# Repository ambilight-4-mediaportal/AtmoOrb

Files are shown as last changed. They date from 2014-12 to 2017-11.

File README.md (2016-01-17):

# AtmoOrb

Projects / showcases using AtmoOrb:

### ESP8266
http://forum.team-mediaportal.com/threads/diy-atmoorb-a-hue-like-mood-lamp-based-on-arduino-esp8266-wifi-module-and-ws2812b-rgb-leds.129229/

### Spark / Particle (Core / Photon)
http://forum.team-mediaportal.com/threads/diy-atmoorb-a-hue-like-mood-lamp-based-on-particle-photon-with-neopixel-tutorial-added.131901/

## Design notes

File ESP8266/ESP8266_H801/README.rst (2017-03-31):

H801 AtmoORB code with status indication
------------------------------------------------------------------------------

The H801 is a very affordable (roughly $10 on Aliexpress) ESP8266 based Wifi
RGB Led controller. It has 5 mosfets accepting input from `5v` to `24v` up to
`4A` with the default configuration. Note that this controller is meant for
dumb RGB(WW) led strips which are _not_ addressable.

The H801 uses `20N06L` mosfets which actually support up to `20A` but I suspect
the rest of the board would burn up if you actually tried it. If you plan to go
beyond the recommend `4A` you should at the very least add some heatsinks to
the mosfets.

The code here makes your H801 behave as a regular AtmoORB but adds a few small
features over the regular ESP8266 code.

1. Since this controller doesn't support addressable leds it drivers the
   mosfets straight away.
2. The controller shows it's status with the 2 status lights on-board.

   1. Whenever the H801 is connected to the wifi network the green led should
      be on.
   2. When the H801 is connecting to the wifi the red led will flash
      periodically (twice per second).
   3. Whenever data is received the red led will flash.

To be able to flash the H801 you will need to solder the headers on the print
yourself. Programming can be done with a regular FTDI programmer but note that
the module _only_ accepts `3.3v` and _will_ burn out if you feed it `5v`.

Some documentation can be found here:
https://eryk.io/2015/10/esp8266-based-wifi-rgb-controller-h801/

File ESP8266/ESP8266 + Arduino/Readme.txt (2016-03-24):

This AtmoOrb version is using an Arduino for the processing and an ESP8266 for WiFi. They communicate via UART (serial) with each other and the EPS8266 AT commands are utilized.
This is an outdated approach and is only kept for legacy support.

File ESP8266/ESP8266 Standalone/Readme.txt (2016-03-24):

You will need to add the ESP8266 platform package to your Arduino IDE Board Manager.
Please follow these installation steps: https://github.com/esp8266/Arduino

Please also make sure that you are using the latest FastLED files.
https://github.com/FastLED/FastLED/archive/master.zip

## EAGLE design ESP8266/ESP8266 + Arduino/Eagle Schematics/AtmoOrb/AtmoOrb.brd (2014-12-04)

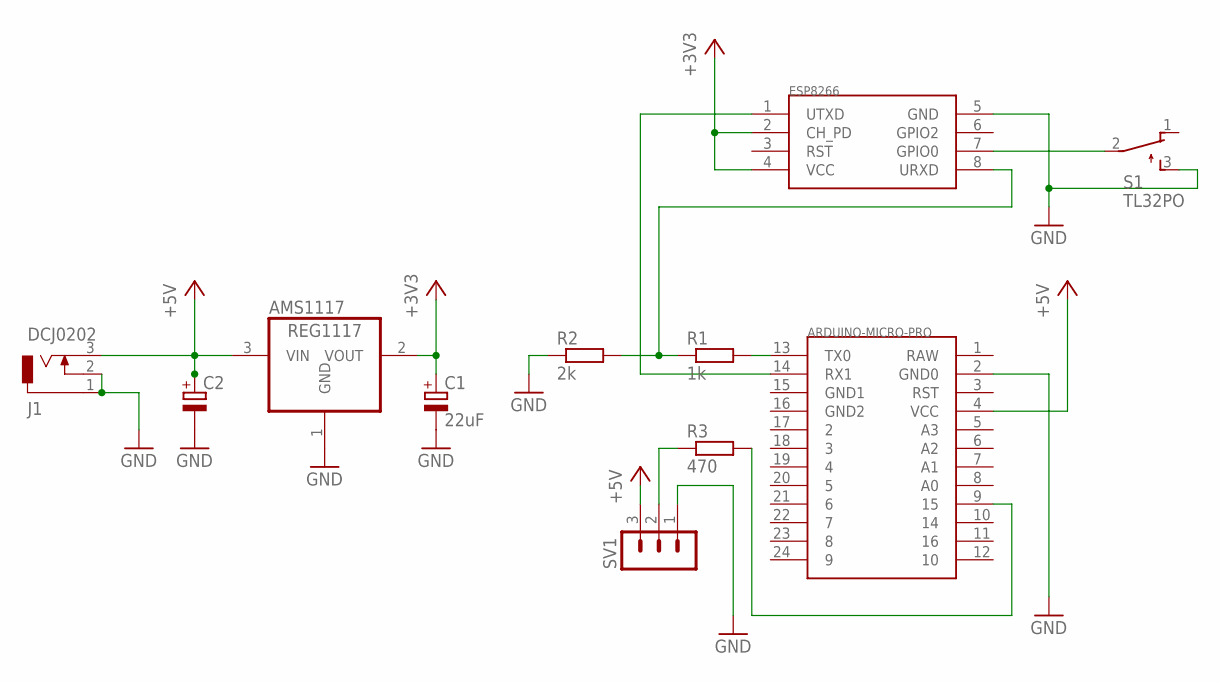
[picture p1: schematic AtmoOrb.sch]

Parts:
AMS1117: REG1117; SOT223
ARDUINO-MICRO-PRO: ARDUINO_MICRO_PRO
C1: 22uF; TAP5-60
C2: CPOL-EUTAP5-60; TAP5-60
ESP8266: ESP8266
J1: DCJ0202
R1: 1k; 0207/10
R2: 2k; 0207/10
R3: 470; 0207/10
S1: TL32PO; TL3XPO
SV1: MA03-1

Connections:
+3V3: AMS1117.2 (VOUT), C1.+, ESP8266.2 (CH_PD), ESP8266.4 (VCC)
+5V: AMS1117.3 (VIN), ARDUINO-MICRO-PRO.4 (VCC), C2.+, J1.3, SV1.3
GND: AMS1117.1 (GND), ARDUINO-MICRO-PRO.2 (GND0), C1.-, C2.-, ESP8266.5 (GND), J1.1, J1.2, R2.1, S1.3 (S), SV1.1
unnamed: ARDUINO-MICRO-PRO.13 (TX0), R1.2
unnamed: ESP8266.8 (URXD), R1.1, R2.2
unnamed: ARDUINO-MICRO-PRO.14 (RX1), ESP8266.1 (UTXD)
unnamed: ARDUINO-MICRO-PRO.9 (15), R3.2
unnamed: R3.1, SV1.2
unnamed: ESP8266.7 (GPIO0), S1.2

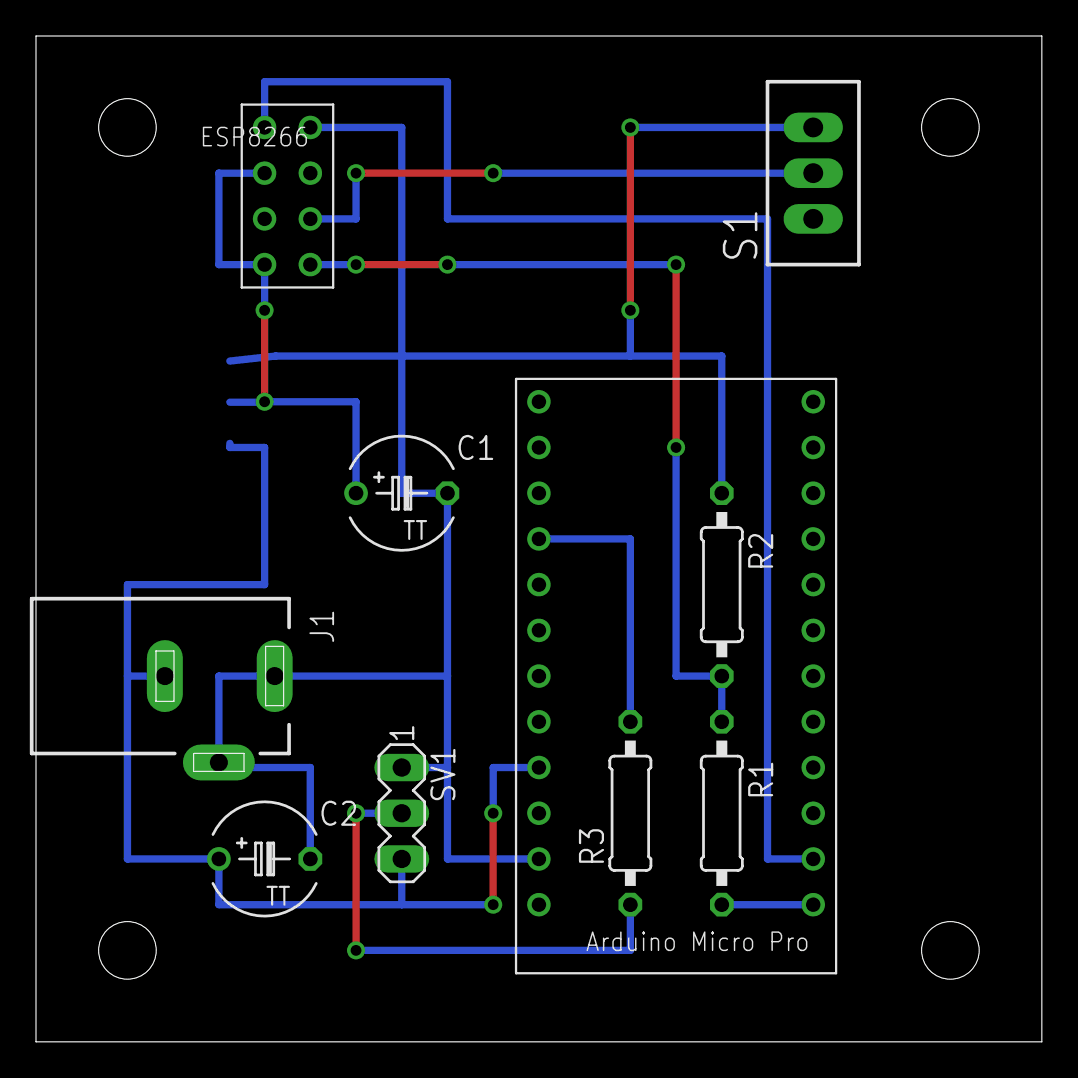
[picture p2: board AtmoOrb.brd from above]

Board: 2 copper layers, 55.9 x 55.9 mm, 11 parts (1 on the bottom side), 9 nets.

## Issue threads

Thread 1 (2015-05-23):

Hyperion support

iLLiac4, 2015-05-23:
Hi. Since it is a remote and it uses actually only one color at the time it would be usefull to try something with ordinary rgb led stripe with pwm and arduino.

Lightning303, 2015-05-24:
Hey,
not sure what exactly you want. Hyperion support or support for "analog" leds stripes? Either way, i am not going to implement these. However, you are of course free to do so :).

Closed 2016-02-05.

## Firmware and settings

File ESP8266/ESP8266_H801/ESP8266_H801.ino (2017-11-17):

// AtmoOrb H801 by Wolph, Lightning303 & Rick164
//
// H801 (ESP8266 based) Version
//
//
// You may change the settings that are commented

#include <ESP8266WiFi.h>
#include <WiFiUDP.h>

#define NUM_LEDS 24 // Number of leds
#define DATA_PIN 7 // Data pin for leds (the default pin 7 might correspond to pin 13 on some boards)
#define SERIAL_DEBUG 1 // Serial debugging (0=Off, 1=On)

#define ID 1 // Id of this lamp

// Smoothing
#define SMOOTH_STEPS 20 // Steps to take for smoothing colors
#define SMOOTH_DELAY 10 // Delay between smoothing steps
#define SMOOTH_BLOCK 0 // Block incoming colors while smoothing

// Startup color
#define STARTUP_RED 255 // Color shown directly after power on
#define STARTUP_GREEN 175 // Color shown directly after power on
#define STARTUP_BLUE 100 // Color shown directly after power on

// White adjustment
#define RED_CORRECTION 220 // Color Correction
#define GREEN_CORRECTION 255 // Color Correction
#define BLUE_CORRECTION 180 // Color Correction

// LED pins
#define PIN_RED 15
#define PIN_GREEN 13
#define PIN_BLUE 12
#define PIN_WHITE1 14
#define PIN_WHITE2 4
#define PIN_STATUS_GREEN 1
#define PIN_STATUS_RED 5

#define ON LOW
#define OFF HIGH

// Network settings
const char* ssid = "ssid"; // WiFi SSID
const char* password = "password"; // WiFi password
const IPAddress multicastIP(239, 15, 18, 2); // Multicast IP address
const int multicastPort = 49692; // Multicast port number

WiFiUDP Udp;
byte nextColor[3];
byte prevColor[3];
byte currentColor[3];
byte smoothStep = SMOOTH_STEPS;
unsigned long smoothMillis;

void setColor(byte red, byte green, byte blue);
void setSmoothColor(byte red, byte green, byte blue);
void smoothColor();
void clearSmoothColors();

void wifiConnect() {
  digitalWrite(PIN_STATUS_GREEN, OFF);
  digitalWrite(PIN_STATUS_RED, OFF);

  int i = 0;
  Serial1.print(F("Connecting to "));
  Serial1.println(ssid);

  while (WiFi.status() != WL_CONNECTED)
  {
    delay(250);
    if (i++ % 2) {
      /* Enable status led */
      digitalWrite(PIN_STATUS_RED, ON);

      /* Write to the console if needed */
#if SERIAL_DEBUG == 1
      Serial1.print(F("."));
#endif
    } else {
      /* Disable status led */
      digitalWrite(PIN_STATUS_RED, OFF);
    }
  }

  /* Enable the green led when connected to Wifi */
  digitalWrite(PIN_STATUS_RED, OFF);
  digitalWrite(PIN_STATUS_GREEN, ON);

#if SERIAL_DEBUG == 1
  Serial1.println("");
  Serial1.print(F("Connected to "));
  Serial1.println(ssid);
  Serial1.print(F("IP address: "));
  Serial1.println(WiFi.localIP());
#endif
}

void setup()
{
  pinMode(PIN_RED, OUTPUT);
  pinMode(PIN_GREEN, OUTPUT);
  pinMode(PIN_BLUE, OUTPUT);
  pinMode(PIN_WHITE1, OUTPUT);
  pinMode(PIN_WHITE2, OUTPUT);
  pinMode(PIN_STATUS_GREEN, OUTPUT);
  pinMode(PIN_STATUS_RED, OUTPUT);

#if SERIAL_DEBUG == 1
  Serial1.begin(115200);
#endif

  WiFi.mode(WIFI_STA);
  WiFi.begin(ssid, password);
  wifiConnect();

  Udp.beginMulticast(WiFi.localIP(), multicastIP, multicastPort);
}

void loop()
{
  if (WiFi.status() != WL_CONNECTED)
  {
#if SERIAL_DEBUG == 1
    Serial1.print(F("Lost connection to "));
    Serial1.print(ssid);
    Serial1.println(F("."));
    Serial1.println(F("Trying to reconnect."));
#endif

    wifiConnect();
  }

  if (Udp.parsePacket())
  {
    digitalWrite(PIN_STATUS_RED, ON);
    
    byte len = Udp.available();
    byte rcvd[len];
    Udp.read(rcvd, len);

#if SERIAL_DEBUG == 1
    Serial1.print(F("UDP Packet from "));
    Serial1.print(Udp.remoteIP());
    Serial1.print(F(" to "));
    Serial1.println(Udp.destinationIP());
    for (byte i = 0; i < len; i++)
    {
      Serial1.print(rcvd[i]);
      Serial1.print(F(" "));
    }
    Serial1.println("");
#endif
    if (len >= 8 && rcvd[0] == 0xC0 && rcvd[1] == 0xFF && rcvd[2] == 0xEE && (rcvd[4] == ID || rcvd[4] == 0))
    {
      switch (rcvd[3])
      {
        case 1:
          setColor(0, 0, 0);
          smoothStep = SMOOTH_STEPS;
          break;
        case 2:
        default:
          setSmoothColor(rcvd[5], rcvd[6], rcvd[7]);
          break;
        case 4:
          setColor(rcvd[5], rcvd[6], rcvd[7]);
          smoothStep = SMOOTH_STEPS;
          break;
        case 8:
          Udp.beginPacket(Udp.remoteIP(), Udp.remotePort());
          Udp.write(ID);
          Udp.endPacket();
          break;
      }
    }
    digitalWrite(PIN_STATUS_RED, OFF);
  }
  if (smoothStep < SMOOTH_STEPS && millis() >= (smoothMillis + (SMOOTH_DELAY * (smoothStep + 1))))
  {
    smoothColor();
  }
}

// Display color on leds
void setColor(byte red, byte green, byte blue)
{
  // Is the new color already active?
  if (currentColor[0] == red && currentColor[1] == green && currentColor[2] == blue)
  {
    return;
  }
  currentColor[0] = red;
  currentColor[1] = green;
  currentColor[2] = blue;

  analogWrite(PIN_RED, red * 4);
  analogWrite(PIN_GREEN, green * 4);
  analogWrite(PIN_BLUE, blue * 4);
}

// Set a new color to smooth to
void setSmoothColor(byte red, byte green, byte blue)
{
  if (smoothStep == SMOOTH_STEPS || SMOOTH_BLOCK == 0)
  {
    // Is the new color the same as the one we already are smoothing towards?
    // If so dont do anything.
    if (nextColor[0] == red && nextColor[1] == green && nextColor[2] == blue)
    {
      return;
    }
    // Is the new color the same as we have right now?
    // If so stop smoothing and keep the current color.
    else if (currentColor[0] == red && currentColor[1] == green && currentColor[2] == blue)
    {
      smoothStep = SMOOTH_STEPS;
      return;
    }

    prevColor[0] = currentColor[0];
    prevColor[1] = currentColor[1];
    prevColor[2] = currentColor[2];

    nextColor[0] = red;
    nextColor[1] = green;
    nextColor[2] = blue;

    smoothMillis = millis();
    smoothStep = 0;
  }
}

// Display one step to the next color
void smoothColor()
{
  smoothStep++;

  byte red = prevColor[0] + (((nextColor[0] - prevColor[0]) * smoothStep) / SMOOTH_STEPS);
  byte green = prevColor[1] + (((nextColor[1] - prevColor[1]) * smoothStep) / SMOOTH_STEPS);
  byte blue = prevColor[2] + (((nextColor[2] - prevColor[2]) * smoothStep) / SMOOTH_STEPS);

  setColor(red, green, blue);
}

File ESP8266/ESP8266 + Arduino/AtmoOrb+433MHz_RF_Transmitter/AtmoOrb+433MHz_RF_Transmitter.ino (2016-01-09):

// AtmoOrb by Lightning303
//
// Developed for:
// "Arduino" Micro Pro
// ESP8266 Module Version 02
// Firmware Version: 0018000902-AI03 (AT 0.18 & SDK 0.9.2)
//
// Pin Connections:
//
// ESP8266
// UTXD           Arduino RX1
// URXD           Arduino TX0 (ESP8266 is 3.3V!)
// VCC            VCC (ESP8266 is 3.3V!)
// GND            GND
// CH_PD          VCC (ESP8266 is 3.3V!)
//
// Arduino
// RX1            ESP8266 UTXD
// TX0            ESP8266 URXD (ESP8266 is 3.3V!)
// VCC            VCC
// GND            GND
// 15             WS2812B Data
//
//
// We are using a baud rate of 19200 here.
// You can either change the ESP8266 baudrate with "AT+CIOBAUD=..."
// or change the program to use another one by editing "Serial1.begin(19200);"

#include "FastLED.h"
#include <RCSwitch.h>

#define NUM_LEDS 27 // Number of leds
#define DATA_PIN 15 // Data pin for leds
#define SLEEP_DELAY 900000 // Delay until RF transmitter sends signals

#define ID "1" // Id of this lamp (can be string or integer)

// Network settings
#define WIFI_SSID "Your WiFi SSID" // SSID of your wifi network
#define WIFI_PASSWORD "Your WiFi Password" // Password to your wifi network
#define DISABLE_DHCP 0 // Disable DHCP
#define STATIC_IP "192.168.1.42" // Static ip if DHCP is disabled
#define BROADCAST_IP "192.168.1.255" // Broadcast ip of your network
#define PORT 49692 // Port you want to use for broadcasting and for the server

// Smoothing
#define SMOOTH_STEPS 50 // Steps to take for smoothing colors
#define SMOOTH_DELAY 4 // Delay between smoothing steps
#define SMOOTH_BLOCK 0 // Block incoming colors while smoothing

// Startup color
#define STARTUP_RED 255
#define STARTUP_GREEN 175
#define STARTUP_BLUE 100

// White adjustment
#define RED_CORRECTION 220
#define GREEN_CORRECTION 255
#define BLUE_CORRECTION 180


CRGB leds[NUM_LEDS];
RCSwitch mySwitch = RCSwitch();
char serialBuffer[500];
String ip;
boolean initialStart = false;
unsigned long previousCheckIP = 0; 
int checkIPInterval = 5000;
byte nextColor[3];
byte prevColor[3];
byte currentColor[3];
byte smoothStep = SMOOTH_STEPS;
unsigned long smoothMillis;
char* readyString = "ready";
char* okString = "OK";
char* noChangeString = "no change";


void setup()
{
  TXLED1;

  FastLED.addLeds<WS2812B, DATA_PIN, GRB>(leds, NUM_LEDS);
  //FastLED.setCorrection(TypicalSMD5050);
  FastLED.setCorrection(CRGB(RED_CORRECTION, GREEN_CORRECTION, BLUE_CORRECTION));

  setSmoothColor(STARTUP_RED, STARTUP_GREEN, STARTUP_BLUE);
  
  mySwitch.enableTransmit(8);
  
  Serial.begin(115200);
  Serial.setTimeout(5);
  Serial1.begin(19200);
  Serial1.setTimeout(5000); 

  // Reset ESP8266
  Serial1.println(F("AT+RST"));
  Serial1.find(readyString);

  // Change to Station mode
  Serial1.println(F("AT+CWMODE=1"));
  Serial1.find(noChangeString);

  // Reset ESP8266
  Serial1.println(F("AT+RST"));
  Serial1.find(readyString);

  // Disable DHCP
  if (DISABLE_DHCP == 1)
  {
    Serial1.println(F("AT+CWDHCP=2,1"));
    Serial1.find(okString);
  }

  // Join access point
  Serial1.setTimeout(10000);
  Serial1.print(F("AT+CWJAP=\""));
  Serial1.print(WIFI_SSID);
  Serial1.print(F("\",\""));
  Serial1.print(WIFI_PASSWORD);
  Serial1.println(F("\""));
  Serial1.find(okString);
  Serial1.setTimeout(5000);

  // Set static ip
  if (DISABLE_DHCP == 1)
  {
    Serial1.print(F("AT+CIPSTA=\""));
    Serial1.print(STATIC_IP);
    Serial1.println(F("\""));
    Serial1.find(okString);
  }

  // Enable multiple connections
  Serial1.println(F("AT+CIPMUX=1"));
  Serial1.find(okString);

  // Setup server
  Serial1.print(F("AT+CIPSERVER=1,"));
  Serial1.println(PORT);
  Serial1.find(okString);

  // Setup client
  Serial1.print(F("AT+CIPSTART=2,\"UDP\",\""));
  Serial1.print(BROADCAST_IP);
  Serial1.print(F("\","));
  Serial1.println(PORT);
  Serial1.find(okString);
  Serial1.setTimeout(5);  
}

void loop()
{
  digitalWrite(17, HIGH);
  if (Serial1.available() > 0)
  {
    int len = Serial1.readBytes(serialBuffer, sizeof(serialBuffer));
    String message = String(serialBuffer).substring(0,len-1);

    // AT 0.20 ip syntax
    if (message.indexOf(F("+CIFSR:")) > -1)
    {
      if (message.indexOf(F("+CIFSR:STAIP")) > -1)
      {
        int start = message.indexOf(F("+CIFSR:STAIP"));
        start = message.indexOf(F("\""), start) + 1; 
        if (isValidIp4(message.substring(start, message.indexOf(F("\""), start))) > 0)
        {
          ip = message.substring(start, message.indexOf(F("\""), start));
          ipReceived();
        }
      }
    }
    // AT pre 0.20 ip syntax
    else if (message.indexOf(F("AT+CIFSR")) > -1)
    {
      int start = message.indexOf(F("AT+CIFSR"));
      start = message.indexOf(F("\n"), start) + 1;
      if (isValidIp4(message.substring(start, message.indexOf(F("\n"), start) - 1)) > 0)
      {
        ip = message.substring(start, message.indexOf(F("\n"), start) - 1);
        ipReceived();
      }
    }
    // Receiving boradcast messages not working with 0020000903, but with 0018000902-AI03
    // Not sure why. But static IP is supported.
    else if (message.indexOf(F("M-SEARCH")) > -1)
    {
      Serial1.println(F("AT+CIFSR"));
    }
    else if (message.indexOf(F("setcolor:")) > -1)
    {
      byte red = -1;
      byte green = -1;
      byte blue = -1;
      int start = message.lastIndexOf(F("setcolor:")) + 9;
      int endValue = message.indexOf(';', start);

      if (endValue == -1 || (endValue - start) != 6)
      {
        return;
      }

      String redHex = message.substring(start, start + 2);
      String greenHex = message.substring(start + 2, start + 4);
      String blueHex = message.substring(start + 4, start + 6);
      
      red = hexToDec(redHex);
      green = hexToDec(greenHex);
      blue = hexToDec(blueHex);
      
      if (red != -1 && green != -1 && blue != -1)
      {    
        setSmoothColor(red, green, blue);
      }
    }
    else if (message.indexOf(F("PING")) > -1)
    {
      String tempString = F("AtmoOrb:");
      tempString += ID;
      tempString += F(":PONG;");
      broadcast(tempString);
    }
    Serial.println(message);
  }
  if (Serial.available() > 0)
  {
    int len = Serial.readBytes(serialBuffer, sizeof(serialBuffer));
    String message = String(serialBuffer).substring(0,len-1);
    Serial1.println(message);
  }
  if (smoothStep < SMOOTH_STEPS && millis() >= (smoothMillis + (SMOOTH_DELAY * (smoothStep + 1))))
  {
    smoothColor();
  }
  if (initialStart && currentColor[0] == 0 && currentColor[1] == 0 && currentColor[2] == 0 && millis() >= smoothMillis + SLEEP_DELAY)
  {
    // Send this signal only once every seconds
    smoothMillis += 1000;
    mySwitch.switchOff("10001", "00010");
  }
  if ((ip == F("") || ip == F("0.0.0.0")) && (millis() - previousCheckIP > checkIPInterval))
  {
    Serial1.println(F("AT+CIFSR"));
    previousCheckIP = millis();
  }
}
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

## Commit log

2014-11-29 Arduino sketch and hardware schematics
    [AtmoOrb.brd, AtmoOrb.sch]
2014-11-30 Added ip retrieval for older ESP8266 firmware. Deleted test code. When commands come in bunched together, only the last one will be used now. Using a millis "timer" now for ip retrieval instead of de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
2014-11-30 Updated schematic and board layout
    [AtmoOrb.brd, AtmoOrb.sch]
2014-12-02 Added folder for CC3000 wifi module and moved ESP8266 stuff into its own folder
    [AtmoOrb.brd, AtmoOrb.sch]
2014-12-03 Added a switch to bring ESP8266 into update mode to schematic and board layout
    [AtmoOrb.brd, AtmoOrb.sch]
2014-12-03 Added UART passthrough sketch to tools
2014-12-08 Fixed smoothing. Before it was using nextColor as prevColor when smoothing got interrupted. This would result in hectic and wrong changes.
    [AtmoOrb.ino]
2014-12-09 Disabled RX and TX leds. Changed smoothing to calculate step size beforehand instead of ad-hoc.
2014-12-14 Added white adjustment. Fixed bug in setSmoothColor. Changed standard port. Code cleanup.
    [AtmoOrb.ino]
2015-09-12 Update AtmoOrb_UDP.ino
    Updated forceleds off to commandOptions
    Removed hostname as its no longer used
    Command option 1 is now force leds off
    [AtmoOrb_UDP.ino]
2015-09-23 Tidy up folders for Particle devices Added udp.setBuffer to Photon UDP sketches
2015-11-24 Particle - disabled forceLedsOFF() as repeated memset requests could crash code in some cases
    [AtmoOrb_UDP.ino]
2015-12-09 Photon UDP - switched to FastLED library and added optional smoothing override
2015-12-10 Photon TCP - switched to FastLED library and added optional smoothing override
2016-01-01 Photon UDP - enabled Particle multi-threading
2016-01-01 Photon TCP - enabled Particle multi-threading
2016-01-05 Photon UDP - added client respawning on WiFi interrupts
2016-01-05 Photon TCP - added client respawning on WiFi interrupts
2016-01-05 Photon UDP - added connectLock to prevent multiple reconnects
    [AtmoOrb_UDP.ino]
2016-01-05 Photon TCP - added connectLock to prevent multiple reconnects
    [AtmoOrb_TCP.ino]
2016-01-08 Photon - added FastLED color corrections for NeoPixel led ring.
    [AtmoOrb_TCP.ino, AtmoOrb_UDP.ino]
2016-01-09 Fixed communication problem between Arduino and ESP8266. Changed the way color correction is calculated. Changed start up color to be shown instantly rather than after wifi connection.
    [AtmoOrb+433MHz_RF_Transmitter.ino, AtmoOrb.ino]
2016-01-10 Photon - can now choose between custom or predefined color corrections
    [AtmoOrb_TCP.ino, AtmoOrb_UDP.ino]
2016-02-05 WiFi check are now called every minute. Corrected code indenting and removed old code.
    [AtmoOrb_TCP.ino, AtmoOrb_UDP.ino]
2016-02-05 Photon - code cleanup and corrections
    [AtmoOrb_TCP.ino, AtmoOrb_UDP.ino]
2016-02-06 Photon - increased WiFi check times. Workaround for firmware issue as clients don't respawn during network interrupts and if WiFi reconnects fast enough the clients don't get recreated.
    [AtmoOrb_TCP.ino, AtmoOrb_UDP.ino]
2016-03-24 Added ESP8266 Standalone support
    [AtmoOrb.brd, AtmoOrb.sch]
2016-03-28 Added RC-Switch lib as Submodule
2016-04-08 Added optional feature to dim the single built-in led in setup().
2016-04-09 ESP8266 fixes. Fixed led data transmission being interrupted. Tweaked smoothing default values. Fixed RCSwitch not working. Added WiFi connection lost debugging. Updated FastLED library.
    [AtmoOrb_ESP8266.ino]
2016-04-11 Photon - enabled smoothing by default and added single led control to TCP as well
2016-05-02 Store smooth color for non-smoothing command type as well. Dim internal Photon led by default.
2016-09-30 Corrected typo in Photon sketches
    [AtmoOrb_TCP.ino, AtmoOrb_UDP.ino]
2016-12-31 Fixed bug in WiFi connection detection
    [AtmoOrb_TCP.ino, AtmoOrb_UDP.ino]
